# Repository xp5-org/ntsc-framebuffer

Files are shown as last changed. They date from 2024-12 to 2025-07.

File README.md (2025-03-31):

NTSC framebuffer built around 74x cmos logic gates and an 128k x 8bit sram module 

** this is incomplete and not yet built, in-progress **

- 8 bits for color + brightness
- 17 bits address
- transfer data in during vblank period

Tasks remaining:
  - complete memory addressing circuitry
  - check gate timings for brightness & color control paths
  - place adjustment potentiometers for setting PNP transistor bias
  - distribute ceramic capacitors
  - add debug testpads onto pcb

# Table of Contents
- [Current PCB Layout](#current-pcb-layout)
- [H&V Counter](#hvcounter)
- [HRESET](#hreset)
- [VRESET](#vreset)
- [HBLANK](#hblank-hsync)
- [VBLANK](#vblank-vsync)
- [COLORBURST](#colorburst)
- [COLORSELECT](#colorselect)
- [BRIGHTNESS](#brightness)
- [MEMORYANDBUS](#memoryandbus)
- [Output Amplifier](#outputamp)
- [Components selection](#components)
- [Simulating](#simtools)

# Current PCB Layout
pcb_infographic
<br>
pcb_infographic_3d
<br><br><br><br><br><br><br><br> 

# hvcounter
This is the core of the circuit, its two 4040 counters, one driving the other. the first counts out 454 which is the number of inactive + active horizontal pixels per row. the output is binary, and with enough AND gates alongside numerous D type flipflops, specific events can be timed out and set to form the sync timings needed

hv_counter_schematicblock

<br><br><br><br><br><br><br><br> 

# HRESET
Screenshot 2025-03-30 at 7 25 06 PM
256 + 128 + 64 + 4 + 2
counts out 454 horizontal & sets HRESET flag to high 5V
and on the next clock pulse from not the timer we are resetting but the actual clock source

<br><br><br><br><br><br><br><br> 

# VRESET
Screenshot 2025-03-30 at 7 37 49 PM
vreset is 1V + 4V + 256V for 261 vertical lines before resetting the counter

vertical reset is checked at the end of the horizontal scanline, so we use _HRESET as the clock for vreset - the condition of 261V lines is set only when _HRESET is ready

# HBLANK-HSYNC
Screenshot 2025-03-30 at 7 38 18 PM
Screenshot 2025-03-30 at 7 38 24 PM

the circuit starts off with some DC bias to give a sync tip from the "previous" scanline, and then at H2 + H8 HBLANK-ENABLE flop is cycled on. When this is on, elsewhere in the circuit the bias is cut off and gives us the horizontal sync tip

When H2 + H8 + H32 is seen (H42) , HBLANK_DISABLE is turned on, which is a 2nd flop "HSYNC B"
Screenshot 2025-03-30 at 8 22 18 PM

this lets me chain the hsync events together with explicit start and stop events, block them from re-triggering

<br><br><br><br><br><br><br><br> 

# VBLANK-VSYNC
Screenshot 2025-03-30 at 7 39 06 PM

<br><br><br><br><br><br><br><br> 

# COLORBURST
Screenshot 2025-03-30 at 7 39 46 PM
Screenshot 2025-03-30 at 7 39 58 PM

<br><br><br><br><br><br><br><br> 

# COLORSELECT
Screenshot 2025-03-30 at 7 41 10 PM
Screenshot 2025-03-30 at 7 41 23 PM
Screenshot 2025-03-30 at 7 41 27 PM

the 4-16 mux is often used for memory addressing and is only available in active-low, so in this case im using NOR gates to invert the signal . the MUX outputs are always high-inactive, so all NOR gates except for the active one are getting a positive voltage which turns them all off, exxcept for the active-low received from the MUX, this NOR gate switches on and provides a color clock at specific delays introduced by the 74AHC451's 4-5ns gate propigation delay
<br><br><br><br><br><br><br><br> 

# BRIGHTNESS
Screenshot 2025-03-30 at 7 42 30 PM
Screenshot 2025-03-30 at 7 42 13 PM

<br><br><br><br><br><br><br><br> 

# MEMORYANDBUS
Screenshot 2025-03-30 at 7 43 53 PM
Screenshot 2025-03-30 at 7 43 57 PM
<br><br><br><br><br><br><br><br> 

# outputamp
The output-amplifier interfaces the low-current, low impedience CMOS or TTL logic with the 1.4v, 75-ohm composite. 

HSYNC, Colorburst, and Pixel Input are given to the amplifiers input. Its first passed through a 2n7000 N-channel mosfet which inverts the signal. This drives a PNP transistor to return it back to positive output, this allowed the GND of the composite-out to also be the same reference plane as the GND of this circuit (pnp could be omitted and use only mosfet with resistor network and floating Gnd)

This has two additional mosfets for saturation bias and output voltage reduction (brightness).  The saturation mosfet biases the PNPs turnoff point "upwards" so that its off point rises above what hsync/hblank would have been . this serves the purpose of adding DC bias to reduce the modulation of the output without affecting the output peak (overall brightness). in summary, this is an amplifier which can control the height of the bottoms and tops of the wave output separately. its needed for color, but could dispose of half the mosfets if it were used for monochrome

Screenshot 2025-03-30 at 8 08 37 PM

<br><br><br><br><br><br><br><br> 

# Components
- 74HC74 D-FLOP
- 74HC08 AND
- 74HC02 NOR
- 74hc244 buffers
- 74hc154 4-to-16 mux
- 74ahc541 inv buffers (color delay line)
- CD4040 12 bit counter
- 14.318mhz crystal
- 128x8 sram HM628128DLP-5
- 2n5087 pnp or equivalent
- 2n7000 mosfet
- 7805 regulator

<br><br><br><br><br><br><br><br> 

# simtools

[LTSpice Model of Output Amplifier](./ltspice_sim/video_output_amplifier.asc)

[Digital Logic simulation](./Digital_sim/ntsc_gen.dig)

output amplifier in ltspice, showing peak brightness vs minimum brightness pixels , there is some distortion in the sim. Some gates are switching on/off before others and causing brief voltage spikes, this might be ignorable on the physical circuit ill have to go through the circuit flow to see what the issue is


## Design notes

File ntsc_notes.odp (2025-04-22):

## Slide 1

NTSC video circuit

Needed a device to scan through a memory chip and put an image on a screen

Wanted it to be universal so it could be adapted to an fgpa, arduino, appleii or whatever

I have an old 70s tv I wanted to use with a tv typewriter style system but didn’t want to use any specific custom impossible to find chips, instead wanted something that could be made out of VHDL or discrete components just as easy in either direction

Also had a number of extra 128k x 8-bit hitachi 70ns SRAM chips and built a project around this

Project can take two directions,

- either a single/multi display monochrome, or only 1 color display. Color info uses a lot more bits than monochrome

The output amplifier stage could be copied & pasted 8x and set each bit from the 1 byte memory to represent 8 different monochrome screens

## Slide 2

What is NTSC

Color Television Simplified Theory and Service Techniques ( Donald G Fink / Philco)

- https://web.archive.org/web/20240521005611/https://www.worldradiohistory.com/BOOKSHELF-ARH/Technology/Technology-General/Color-Television-Simplified-Theory-Philco-19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

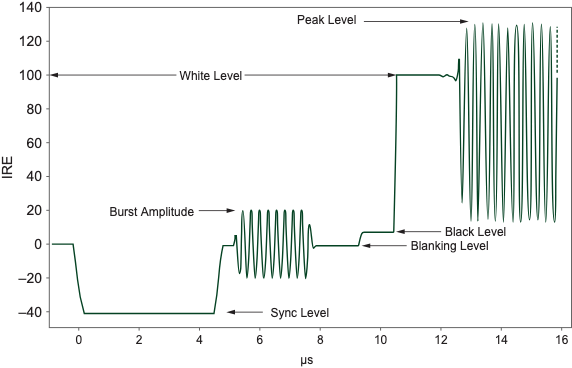
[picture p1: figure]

There is a 300 page philco book about NTSC in great detail, I wont even attempt to repeat what is said in it

Its difficult to avoid discussing what NTSC is – when reviewing over an NTSC video card circuit and how it was built. There is a lot of information online about the history of NTSC, why it is the way it is. but as far as “What it is” – its all in this simplified waveform diagram

in summary:

Its a DC-biased high frequency analog signal , 1.4v peak-to-peak with a negative pulse to synchronize the receiver at roughly 15khz. The Receiving CRT tv aligns itself to this HSYNC pulse each horizontal row of pixels (each scanline) so it knows when its time start drawing & when to advance down the next row

Atop of this HSYNC period, if color is used, is a 2nd sync pulse (Colorburst) to start the timer of an analog circuit related to color in the receiver. When colorburst is present , a color receiver will look at the pixel pulses/signal, and depending on what the phase-shift is of that signal (in reference to its own timer that was just synchronized moments ago), it will “move” or position the drawing on the screen to overlap either the RGB phosphors

When the receiving tv sees this “hblank” pulse, it uses the levels right after to set its various analog circuits, so they know what their turn off levels are (full-dark). On this blanking level is where color magic is shoehorned in

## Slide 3

Color in NTSC is determined by the amount of phase-shift, between the colorburst reference signal and the signal received for a given pixel. NTSC doesn’t have concepts of pixels, its just a analog voltage appearing on a line and then decaying at set intervals which roughly correspond to different positions on the screen (which we can call pixels) but mechanically speaking its a stopwatch paired to a trio of R/G/B laserbeams. HSYNC starts the stopwatch1 (draw the pixels timer) , and colorburst starts stopwatch2 (bias the output voltages left or right)

this rise-and-fall of pixel data, is drawn against an oscillator previously locked to the colorburst reference and any phase shift here will be pushing the point of luminosity left-or-right , thus shifting the color in the pattern represented by the following “NTSC color wheel”. So, the phase-shift represents the HUE of the color we see (with 1:1 lock to the reference being equal red-green-blue, or what we would perceive as white)

to be clear the electron beam is not moved or altered by colorburst. It is simply that the voltage-peak is higher earlier-or-later, at the time when its no longer perfectly overlapping the 3 RGB cells, so a 90 degree shift will have 2 half-blues 1 red and 1 green illuminated in perspective from starting at white.

Analogy: Imagine a person listening to an echo at a tunnel with a stopwatch on a gameshow. The show has a big wooden spinning color wheel which begin rotating by a motor when the show host fires a starting pistol (the colorburst timer). The longer the delay between the original sound and the echo, the more “time” translates to color shift and when the echo is herd the person stops the color wheel, and the color they land on is their score. The wheel never stops spinning, and the starting pistol is only fired once per round, so the contestant is reliant upon their stopwatch for good accurate scores

do this enough and can see that different colors happen at different exact predictable times (echos) given the tunnel length & wheel speed (clock frequency) stays the same. This is an analog way to convey lots of info (full color pallet)

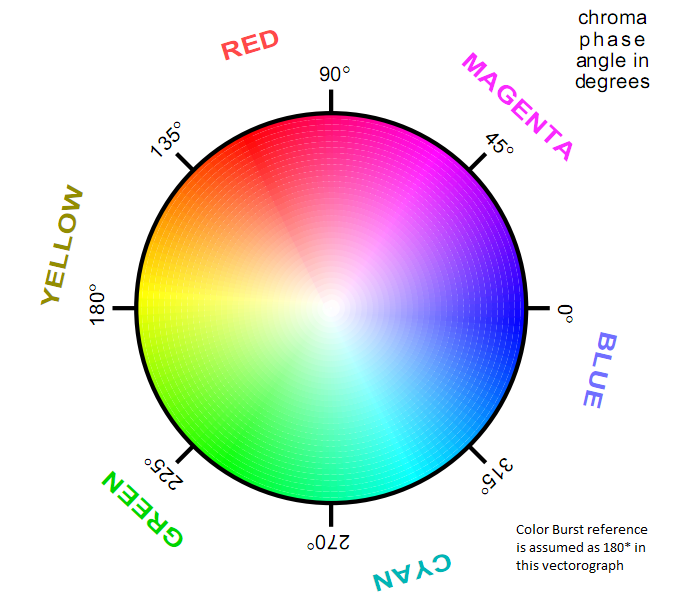
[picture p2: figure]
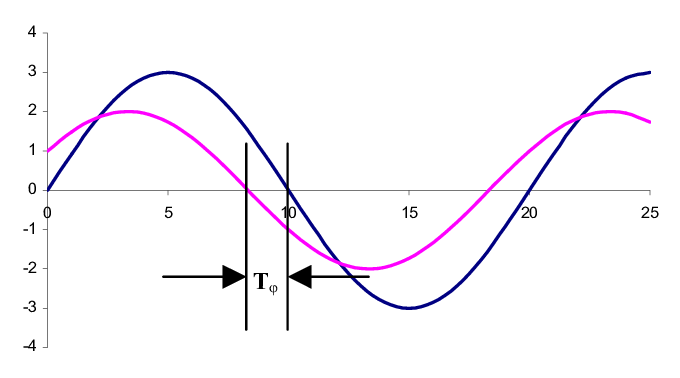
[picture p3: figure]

Phase shift of input pixel data changes appearance of timing of output to the electron guns so we are shifting left or right the intensity of the beam against phosphor **but not the beam itself**

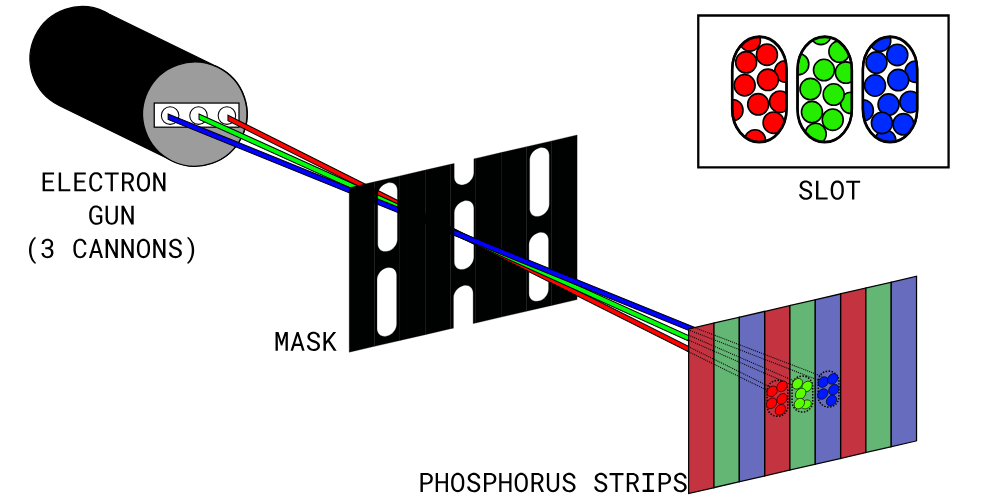
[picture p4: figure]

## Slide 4

https://www.rfcafe.com/references/radio-news/color-tv-ntsc-system-radio-television-news-april-1954.htm

NTSC color wheel in references look like this

red is (BY) – 103, or (RY) - 13

Yellow is (BY) – 167

Yellow also (-BY) + 13

Green (-BY) -61
Blue (BY) – 13

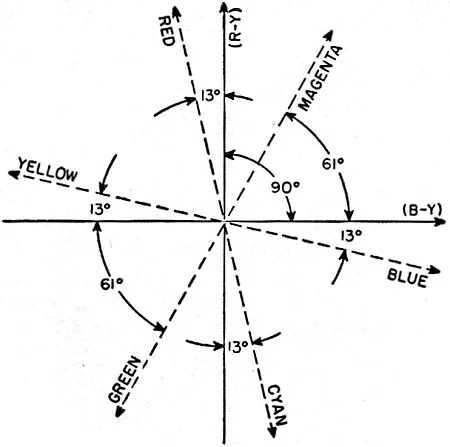
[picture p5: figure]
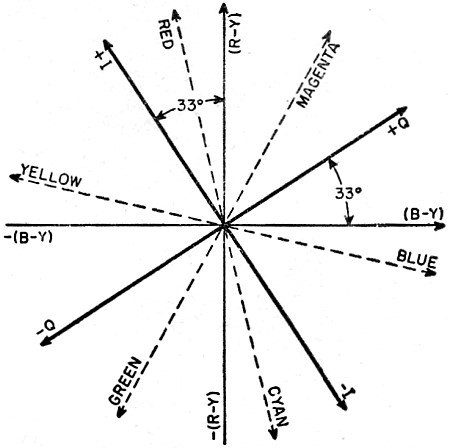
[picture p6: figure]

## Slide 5

Emphasis on: “the electron beam is not moved or altered”

We can’t (thats not how it works)

The CRT uses electromagnetic deflection coils which are very heavy components electrically, these are cycled at roughly 15khz . “pixels” on the screen are nearly 4mhz, so if we want to influence anything to do with pixels and how they appear on screen we have to rely on only this:

- changing beam intensity at specific points in time (electron gun is tiny and fast)

NTSC was designed to accommodate CRT display tubes, this means every design consideration is there to accommodate the mechanical behaviors of CRTs

- electron beam, phosphor screen, timings, color levels

For those using a modern display : None of this is directly useful to an LCD screen, so an LCD screen with composite in will be using an analog-digital type circuit to read the voltages at specific times and determine what a pixel is and what color it probably is. The artifacting and accuracy of what is shown will vary

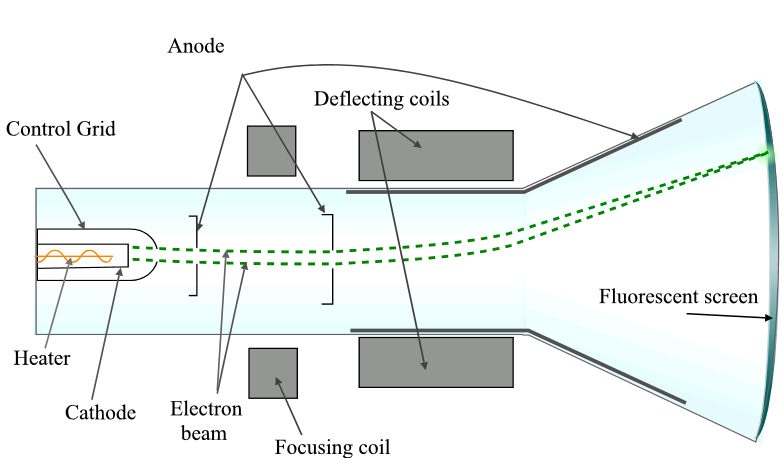
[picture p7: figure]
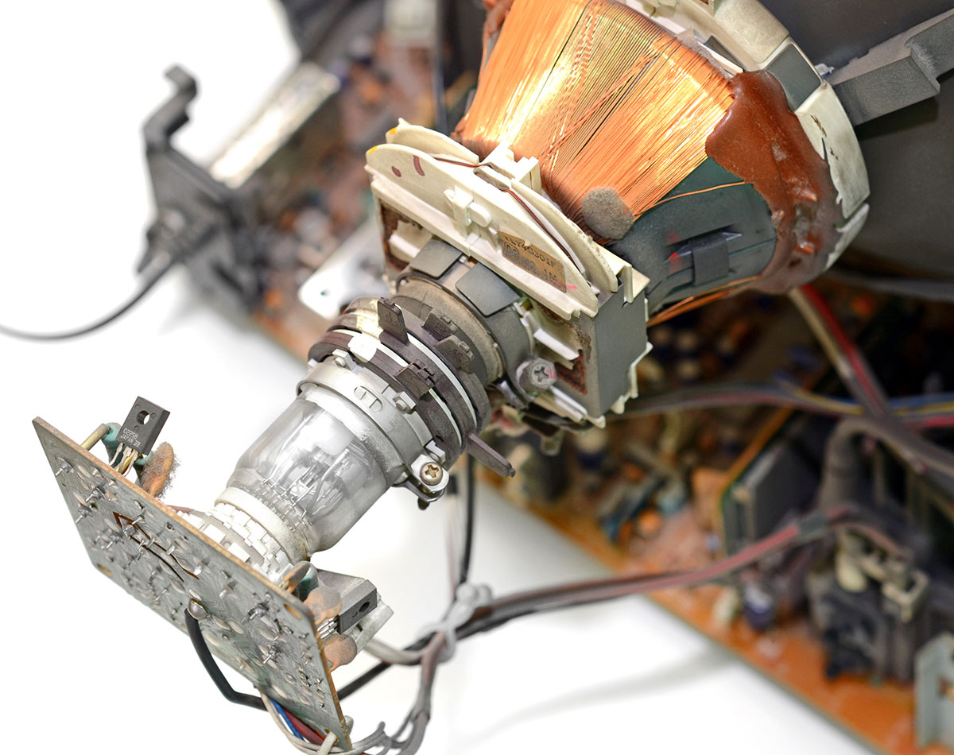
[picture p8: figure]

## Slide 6

Ive shown the NTSC color wheel from a 2D view, but that isnt the full story. NTSC has the concepts of “brightness” and “Saturation” as representation of signal intensities. But in the 2d view notice it is brighter or more pastel in the center

Here im showing the 2D color view, and the 3D reality which happens with over-saturation or overdrive

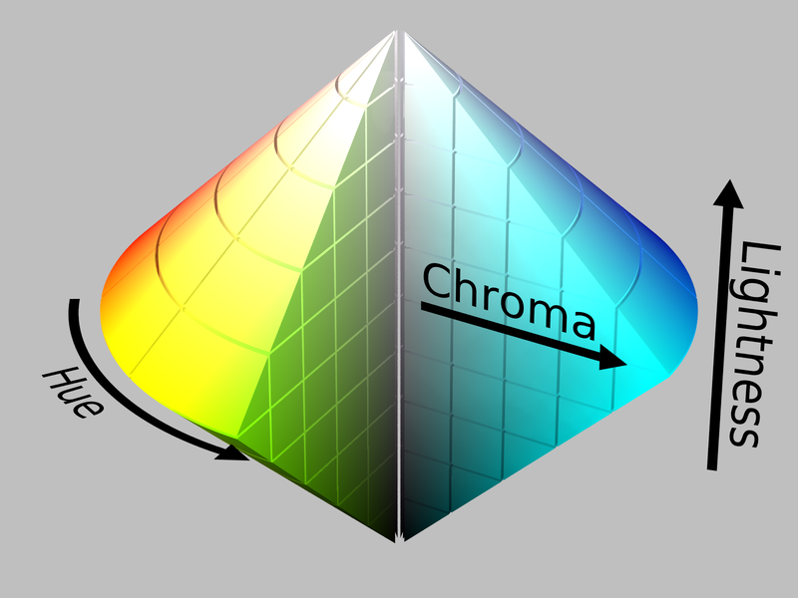
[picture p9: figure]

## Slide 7

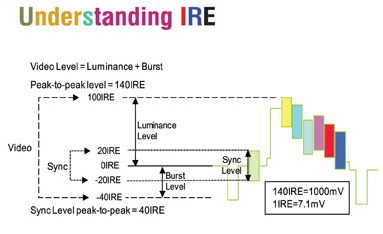
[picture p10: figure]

To discuss the 3d NTSC cone shape, need to go over the levels. More intensity doesn’t exactly mean “more of whatever color is happening right now”, it can mean (especially on a CRT set) color bleedover into adjacent cells as what might’ve been intended to be 50% cell1 50% cell2 illumination with proper biasing, too much intensity could result in 100% cell1 and 100% cell2 which results in the WRONG COLOR

With the HSYNC period having set the “black level” (which is the period at which the electron beam is turned off by its analog amplifier inside the receiver tv)

NTSC is originally a black and white concept with color added on as not a topic of levels, but one of phase-shift as we saw previously.

This is done by changing the MODULATION of the output signal, as in, keeping the peak voltage high but raising the DC bias upwards, reduces saturation and reduces the influence of this colorburst phase-shift making the image appear more gray and, well, less saturated.

So in review NTSC has these 3 key things:

HSYNC timing (start + stop time period, voltage level) – This sets when each new scanline starts and gets the show started and must be microsecond precise

Signal height (bias + peak to peak measurement) – translates to electron gun beam intensity or brightness. Its 0-1.4v

Signal amplitude (peak-to-peak, disregard bias) : More amplitude = less gray, less amplitude = more gray. controls amount of time/intensity electron beam is kept “away” from turnoff point and results in color cells always getting some intensity, which ‘grays’ out the image

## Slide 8

Going further into saturation & levels, different colors have requirements for both biasing the DC floor upwards (reduce saturation) or lowering it below black levels.

Red, Blue need to be modulated less than yellow or cyan, but have a lower starting point – this translates to less intensity on the electron beam and is nearly turning off, has to do with how the colors on a CRT phosphors are blending in

yellow and cyan are red + blue but need to keep the electron guns drive hot and vibrant almost white, so these colors are “biased upwards”

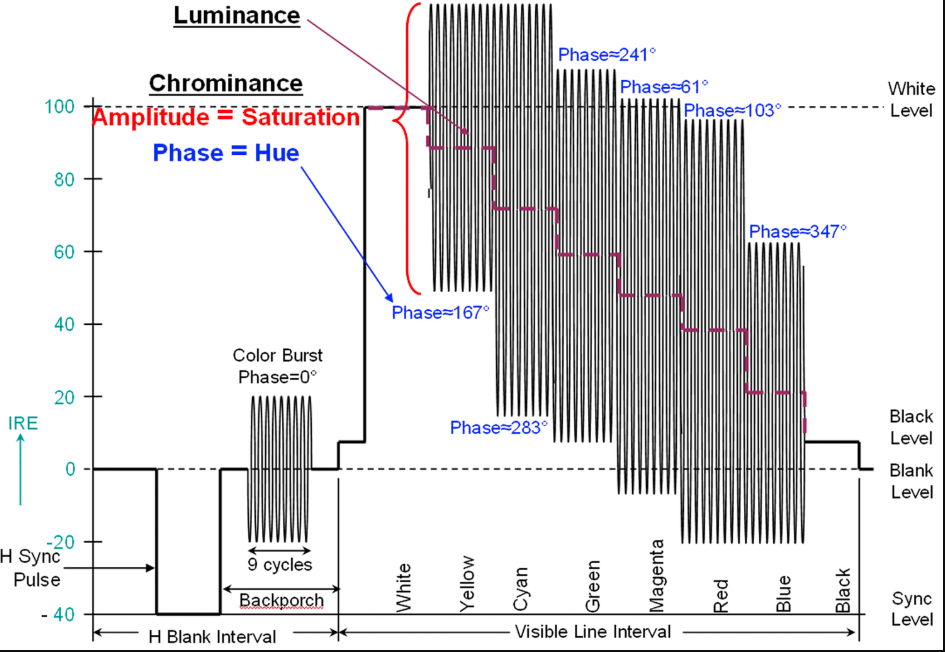
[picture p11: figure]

When you look at things like this, color on NTSC really seems like someone just slapped in a phosphor grid into a B&W set and used a few tricks to make the beam blink in the right spot at the right time.

Its clever but there are a lot of layers of cleverness to unpack

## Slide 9

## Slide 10

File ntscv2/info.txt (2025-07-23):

/ntscv2$ grep '(global_label' ntscv2.kicad_sch | sed -n 's/.*"\([^"]*\)".*/\1/p' | sort | uniq -c | sort -n | tail -n15
      4 H4
      4 H64
      4 HSYNCB
      4 m1_data4
      4 m1_data5
      4 m1_data6
      4 m1_data7
      4 PIXELDRAWEN
      5 H8
      6 H1
      6 H2
      6 VRESET
      7 CDL_output_enable
      8 _HRESET
      9 _VBLANK_BUFFERED

shows number of gates connected to a global label to get an idea for fanout load

READ:
CS1 - L
CS2 - H
OE - L
WE - H

WRITE:
READ:
CS1 - L
CS2 - H
OE - L or H
WE - L

A write occurs during the overlap of a low CS1, a high CS2, and a low WE. A write begins at the
latest transition among CS1 going low, CS2 going high, and WE going low. A write ends at the
earliest transition among CS1 going high, CS2 going low, and WE going high. tWP is measured
from the beginning of write to the end of write

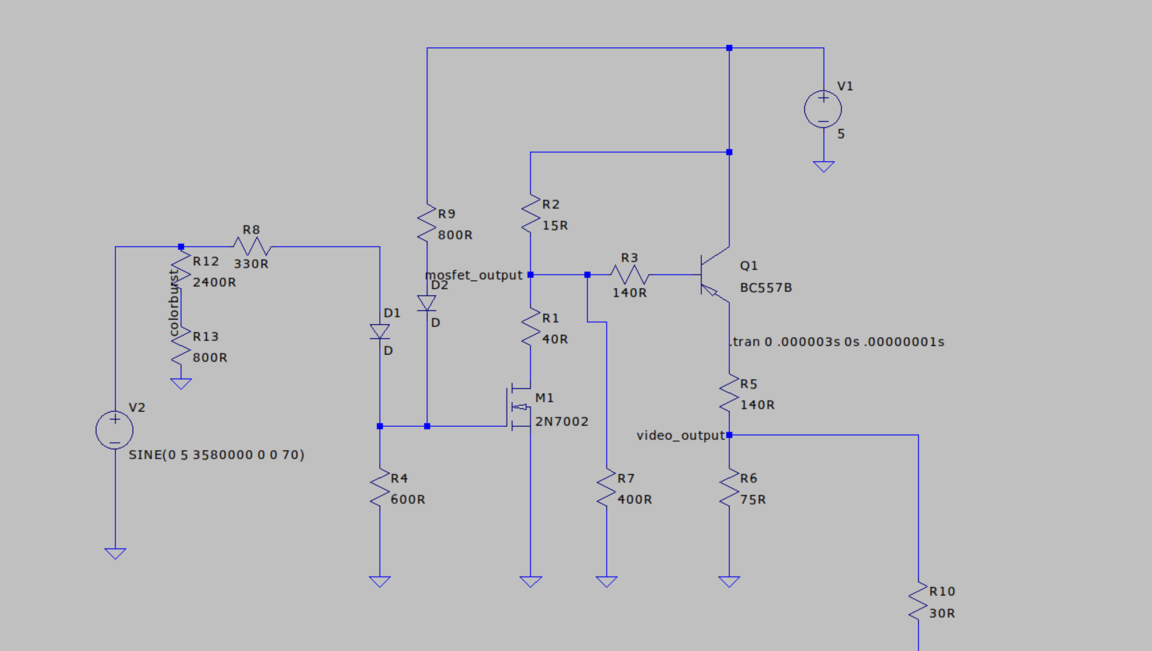
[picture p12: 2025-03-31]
ltspice_sim/BC557B_scematic.png

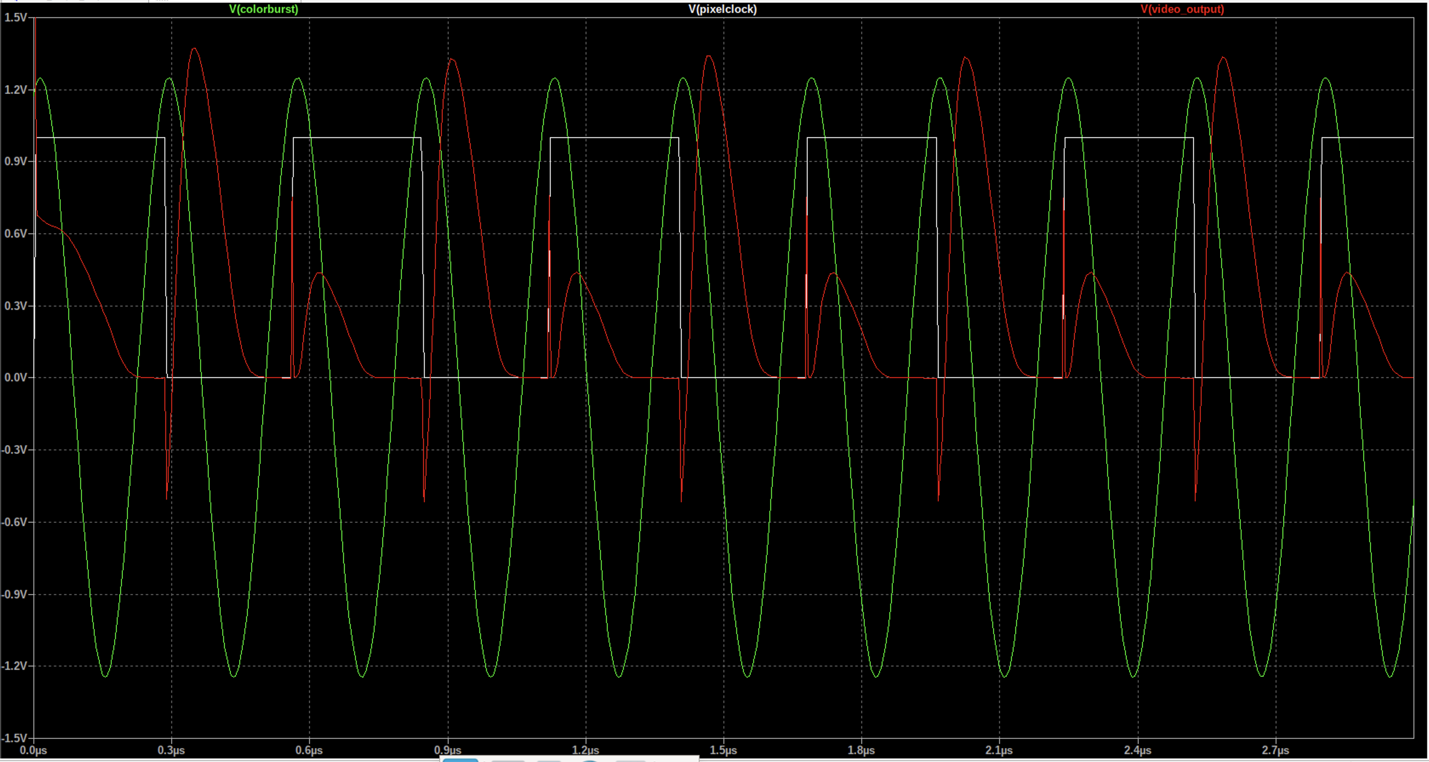
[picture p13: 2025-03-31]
ltspice_sim/BC557B_waveform.png

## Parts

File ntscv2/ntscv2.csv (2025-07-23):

Reference | Qty | Value | DNP | Exclude from BOM | Exclude from Board | Footprint | Datasheet
C3,C4,C5,C6,C7,C8,C9,C10,C11,C12,C13,C14,C15,C17,C19,C20,C21,C22,C23,C24,C25,C26,C27,C28,C29,C30,C31,C32,C33,C34,C35,C36,C37,C38,C39,C40,C41 | 37 | C |  |  |  | Capacitor_SMD:C_0603_1608Metric | ~
R30,R33,R35,R36,R37,R38,R39,R40,R41,R42,R43,R44,R45,R46,R47,R48,R49,R50,R51,R52,R53,R54,R55,R56,R57,R58,R59,R60,R61,R62,R63,R64,R65,R66,R67,R68 | 36 | 10k |  |  |  | Resistor_SMD:R_0402_1005Metric_Pad0.72x0.64mm_HandSolder | ~
D6,D7,D8,D9,D10,D11,D12,D13,D14,D15,D16,D17,D18,D19,D20,D21,D22,D23,D24,D25,D26,D27,D28,D29,D30,D31,D32,D33,D34,D35,D39 | 31 | 1N4148 |  |  |  | Diode_SMD:D_SOD-323 | https://assets.nexperia.com/documents/data-sheet/1N4148_1N4448.pdf
R9,R10,R15,R16,R17,R18,R19,R20,R21,R22,R23,R24,R25,R26,R27,R28,R29 | 17 | R |  |  |  | Resistor_SMD:R_0603_1608Metric | ~
R2,R3,R4,R5,R6,R7,R11,R12,R13,R14 | 10 | R |  |  |  | Resistor_THT:R_Axial_DIN0204_L3.6mm_D1.6mm_P5.08mm_Horizontal | ~
D1,D2,D3,D4,D5,D36,D37,D38,D41,D42 | 10 | 1N4448 |  |  |  | Diode_SMD:D_SOD-323 | https://assets.nexperia.com/documents/data-sheet/1N4148_1N4448.pdf
U5,U6,U7,U12,U13,U14,U27,U29,U31 | 9 | 74HC244 |  |  |  | Package_SO:TSSOP-20_4.4x6.5mm_P0.65mm | https://assets.nexperia.com/documents/data-sheet/74HC_HCT244.pdf
C42,C43,C44,C45,C46,C47,C48,C49 | 8 | 20uF 16v |  |  |  | Capacitor_SMD:C_1206_3216Metric | ~
U1,U2,U3,U4,U15,U16,U38 | 7 | 74AHC08D |  |  |  | Package_SO:SO-14_3.9x8.65mm_P1.27mm | http://www.intersil.com/content/dam/Intersil/documents/cd40/cd4073bms-81bms-82bms.pdf,https://jlcpcb.com/partdetail/Nexperia-74AHC08D118/C5506
U8,U9,U10,U11,U19 | 5 | 74HCT74 |  |  |  | Package_SO:SO-14_3.9x8.65mm_P1.27mm | https://www.ti.com/lit/ds/symlink/sn74hc74.pdf
U32,U33,U36,U37 | 4 | 74HC02 |  |  |  | Package_SO:SOIC-14_3.9x8.7mm_P1.27mm | http://www.ti.com/lit/gpn/sn74hc02,https://jlcpcb.com/partdetail/Nexperia-74HC02PW118/C113211
U18,U21,U23,U24 | 4 | 4040 |  |  |  | Package_SO:SOIC-16W_5.3x10.2mm_P1.27mm | http://www.intersil.com/content/dam/Intersil/documents/cd40/cd4020bms-24bms-40bms.pdf
H1,H2,H3,H4 | 4 | MountingHole_Pad |  | Excluded from BOM |  | MountingHole:MountingHole_2.7mm_M2.5_DIN965_Pad | ~
RV1,RV2,RV4 | 3 | R_Potentiometer |  |  |  | mysymbols_footprint:TRIM_3362P-1-100LF | ~
R31,R32,R34 | 3 | 10k |  |  |  | Resistor_SMD:R_0603_1608Metric | ~
Q1,Q2,Q4 | 3 | 2N7000 |  |  |  | Package_TO_SOT_THT:TO-92_Inline | https://www.vishay.com/docs/70226/70226.pdf
U34,U35 | 2 | 74HC540D_653 |  |  |  | Package_SO:SOIC-20W_7.5x12.8mm_P1.27mm
U26,U30 | 2 | 74HC154PW |  |  |  | Package_SO:TSSOP-24_4.4x7.8mm_P0.65mm | https://jlcpcb.com/partdetail/Nexperia-74HC154PW118/C21061,https://www.ti.com/lit/ds/symlink/cd74hc154.pdf
U22,U25 | 2 | 74HC04 |  |  |  | Package_SO:SOIC-14_3.9x8.7mm_P1.27mm | https://assets.nexperia.com/documents/data-sheet/74HC_HCT04.pdf
C50,C51 | 2 | 10uF 25V |  |  |  | Capacitor_SMD:C_1206_3216Metric | ~
C1,C2 | 2 | 15pF |  |  |  | Capacitor_SMD:C_0603_1608Metric | ~
Y1 | 1 | Crystal |  |  |  | Crystal:Crystal_HC49-U_Vertical | ~
U28 | 1 | LM7805_TO220 |  |  |  | Package_TO_SOT_THT:TO-220-3_Vertical | https://www.onsemi.cn/PowerSolutions/document/MC7800-D.PDF
U20 | 1 | 74HC245D |  |  |  | Package_SO:TSSOP-20_4.4x6.5mm_P0.65mm | https://www.nexperia.com/product/74HC245D
U17 | 1 | HM628128ALFP-5 |  |  |  | Package_DIP:DIP-32_W15.24mm
TP88 | 1 | FIELD0 |  |  |  | mysymbols_footprint:TestPoint_Pad_0.8x0.8mm | ~
TP87 | 1 | FIELD1 |  |  |  | mysymbols_footprint:TestPoint_Pad_0.8x0.8mm | ~
TP86 | 1 | CB_DIS |  |  |  | mysymbols_footprint:TestPoint_Pad_0.8x0.8mm | ~
TP85 | 1 | CBEN |  |  |  | mysymbols_footprint:TestPoint_Pad_0.8x0.8mm | ~
TP84 | 1 | PIXELDRAWEN |  |  |  | mysymbols_footprint:TestPoint_Pad_0.8x0.8mm | ~
TP83 | 1 | VRESET |  |  |  | mysymbols_footprint:TestPoint_Pad_0.8x0.8mm | ~
TP82 | 1 | HRESET |  |  |  | mysymbols_footprint:TestPoint_Pad_0.8x0.8mm | ~
TP81 | 1 | VBLANK |  |  |  | mysymbols_footprint:TestPoint_Pad_0.8x0.8mm | ~
TP80 | 1 | HSYNCA |  |  |  | mysymbols_footprint:TestPoint_Pad_0.8x0.8mm | ~
TP79 | 1 | HSYNCB |  |  |  | mysymbols_footprint:TestPoint_Pad_0.8x0.8mm | ~
TP7 | 1 | HSYNC_input |  |  |  | mysymbols_footprint:TestPoint_Pad_0.8x0.8mm | ~
TP6 | 1 | Pixeldrive_input |  |  |  | mysymbols_footprint:TestPoint_Pad_0.8x0.8mm | ~
TP5 | 1 | CB_Source |  |  |  | mysymbols_footprint:TestPoint_Pad_0.8x0.8mm | ~
RV3 | 1 | 100R |  |  |  | mysymbols_footprint:TRIM_3362P-1-100LF | ~
R8 | 1 | ~ |  |  |  | Resistor_SMD:R_0603_1608Metric | ~
R1 | 1 | 6k |  |  |  | Resistor_SMD:R_0603_1608Metric | ~
Q3 | 1 | BC327 |  |  |  | Package_TO_SOT_THT:TO-92_Inline | http://www.onsemi.com/pub_link/Collateral/BC327-D.PDF
J3 | 1 | Conn_01x02 |  |  |  | Connector_PinHeader_2.54mm:PinHeader_1x02_P2.54mm_Vertical | ~
J2 | 1 | Conn_Coaxial |  |  |  | Connector_Coaxial:BNC_TEConnectivity_1478035_Horizontal | ~
J1 | 1 | Conn_02x20_Odd_Even |  |  |  | Connector_PinHeader_2.54mm:PinHeader_2x20_P2.54mm_Vertical | ~

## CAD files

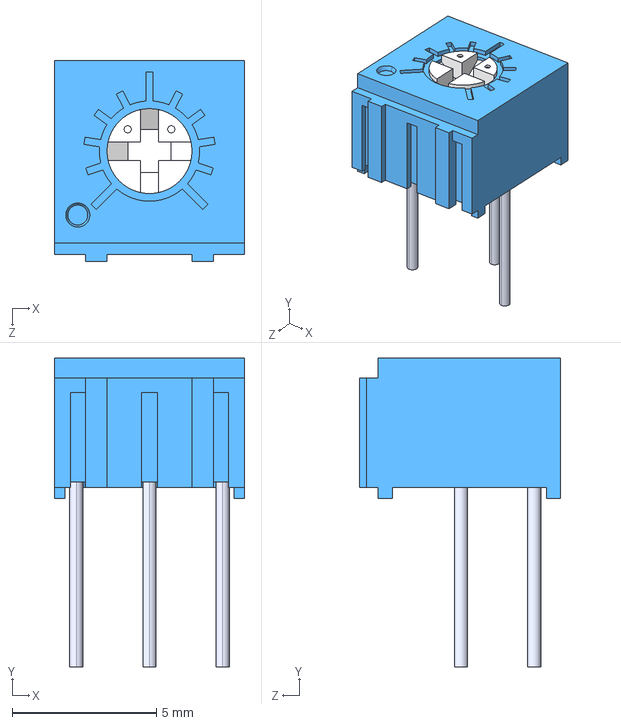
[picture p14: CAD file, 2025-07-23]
ntscv2/3362P-1-100LF.step
6.60 x 10.7 x 6.99 mm

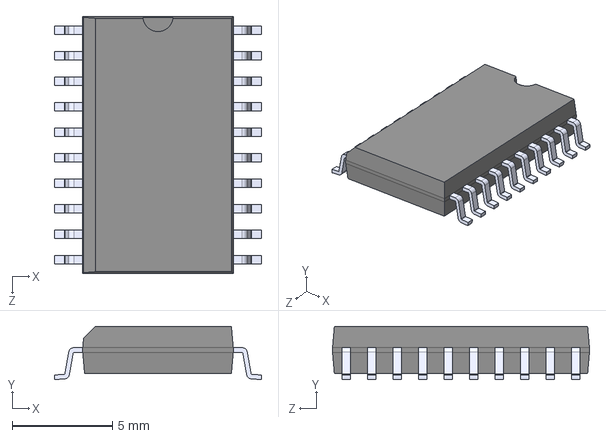
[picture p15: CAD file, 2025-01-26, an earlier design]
old_deletesoon/ntsc_syncgen_kicad/downloaded_symbols/74HC540D_653/74HC540D_653.step
10.3 x 2.65 x 12.8 mm

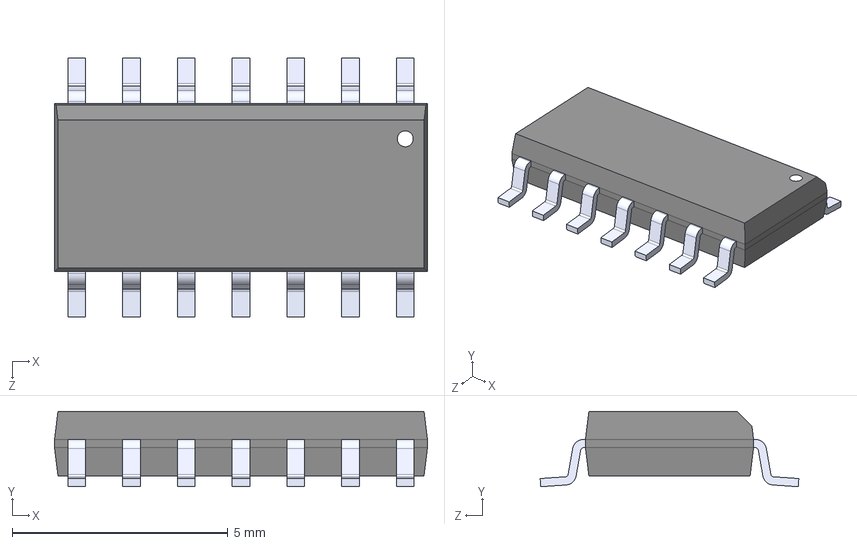
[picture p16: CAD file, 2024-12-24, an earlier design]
old_deletesoon/ntsc_syncgen_kicad/downloaded_symbols/SN74AHC74DR/SN74AHC74DR.step
8.65 x 1.75 x 6.00 mm

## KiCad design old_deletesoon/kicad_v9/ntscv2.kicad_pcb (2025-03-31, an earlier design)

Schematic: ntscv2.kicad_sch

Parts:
C1, C4, C5, C6, C7, C8, C9, C10, C11, C12, C13, C14, C15, C16, C17, C18, C19, C20, C21, C22, C23, C24, C25, C27: C; C_Disc_D5.1mm_W3.2mm_P5.00mm
C2, C3: 10pF; C_Disc_D3.0mm_W2.0mm_P2.50mm
C26: C; C_Radial_D8.0mm_H7.0mm_P3.50mm
D1, D2, D3, D4, D5: 1N4448; D_DO-35_SOD27_P7.62mm_Horizontal
D6, D7, D8, D9, D10, D11, D12, D13, D14, D15, D16, D17, D18, D19, D20, D21, D22, D23, D24, D25, D26, D27, D28, D29, D30, D31, D32, D33, D34, D35, D36: 1N4148; D_DO-35_SOD27_P7.62mm_Horizontal
J1: Conn_Coaxial; BNC_TEConnectivity_1478035_Horizontal
J2: Conn_02x04_Counter_Clockwise; PinSocket_2x04_P2.54mm_Vertical
J3: Conn_02x20_Counter_Clockwise; PinSocket_2x20_P2.54mm_Vertical
Q1: BC327; TO-92_Inline
Q2, Q3, Q4: 2N7000; TO-92_Inline
R1, R3, R4, R5, R6, R7, R8, R9, R10, R11, R12, R13, R14, R15, R16, R17, R18, R19, R20, R21, R22, R23, R24, R25, R26, R27, R28, R29, R30: R; R_Axial_DIN0204_L3.6mm_D1.6mm_P5.08mm_Horizontal
R2: 680; R_Axial_DIN0204_L3.6mm_D1.6mm_P7.62mm_Horizontal
R31, R32, R33: 50R; R_Axial_DIN0204_L3.6mm_D1.6mm_P5.08mm_Horizontal
U1, U2, U3, U4, U5, U40: 74HCT74; SO-14_3.9x8.65mm_P1.27mm
U6, U7, U14, U15: 4040; DIP-16_W7.62mm_SMDSocket_SmallPads
U8: 74HC7014; SOIC-14_3.9x8.7mm_P1.27mm
U9, U10, U11, U13: 4081; DIP-14_W7.62mm
U12: 4081; SO-14_3.9x8.65mm_P1.27mm
U16, U30: 74154; SOIC-24W_7.5x15.4mm_P1.27mm
U17, U18, U21: 74AHC541; SOIC-20W_7.5x12.8mm_P1.27mm
U19, U20, U22, U23: 74HC02; SOIC-14_3.9x8.7mm_P1.27mm
U24, U25, U26, U27, U28, U29, U31, U32: 74HC244; SSOP-20_4.4x6.5mm_P0.65mm
U33: HM628128ALFP-5; DIP-32_W15.24mm; PARTREV 20/6/13
U34, U35: 74HC540D_653; SOIC-20W_7.5x12.8mm_P1.27mm; MPN 74HC540D,653
U46: LM7805_TO220; TO-220-3_Vertical
Y1: Crystal; Crystal_HC49-U_Vertical

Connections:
1H: U6.9 (Q0), U17.2 (A0), U19.2
1V: U7.9 (Q0), U10.1
2H: U6.7 (Q1), U9.1
2V: U7.7 (Q1)
4H: U6.6 (Q2), U9.2
4V: U7.6 (Q2), U10.5
5vdc: C1.1, C4.1, C5.1, C6.1, C7.1, C8.1, C9.1, C10.1, C11.1, C12.1, C13.1, C14.1, C15.1, C16.1, C17.1, C18.1, C19.1, C20.1, C21.1, C22.1, C23.1, C24.1, C25.1, C26.1, J2.1, J2.2, Q1.1 (C), R12.1, U1.10 (~S), U1.13 (~R), U1.14 (VCC), U2.10 (~S), U2.13 (~R), U2.14 (VCC), U3.2 (D), U3.4 (~S), U3.10 (~S), U3.12 (D), U3.14 (VCC), U4.2 (D), U4.4 (~S), U4.10 (~S), U4.12 (D), U4.14 (VCC), U5.2 (D), U5.4 (~S), U5.10 (~S), U5.12 (D), U5.14 (VCC), U6.16 (VDD), U7.16 (VDD), U8.14 (VCC), U9.14 (VDD), U10.14 (VDD), U11.14 (VDD), U12.14 (VDD), U13.14 (VDD), U14.16 (VDD), U15.16 (VDD), U16.24 (VCC), U17.20 (VCC), U18.20 (VCC), U19.14 (VCC), U20.14 (VCC), U21.20 (VCC), U22.14 (VCC), U23.14 (VCC), U24.20 (VCC), U25.20 (VCC), U26.20 (VCC), U27.20 (VCC), U28.20 (VCC), U29.20 (VCC), U30.24 (VCC), U31.20 (VCC), U32.20 (VCC), U33.32 (VCC), U34.20 (VCC), U35.20 (VCC), U40.1 (~R), U40.4 (~S), U40.10 (~S), U40.13 (~R), U40.14 (VCC), U46.3 (VO)
7.1mhz_CLK1: U1.5 (Q), U6.10 (CLK), U7.10 (CLK)
8H: U6.5 (Q3)
8V: U7.5 (Q3)
14mhz_CLK0: U1.3 (C), U2.3 (C), U8.6, U8.8, U8.10
16H: U6.3 (Q4)
16V: U7.3 (Q4)
32H: U6.2 (Q5)
32V: U7.2 (Q5)
64H: U6.4 (Q6), U9.5
64V: U7.4 (Q6)
128H: U6.13 (Q7), U9.6
128V: U7.13 (Q7)
256H: U6.12 (Q8), U9.13
256V: U7.12 (Q8), U10.6
512H: U6.14 (Q9)
512V: U7.14 (Q9)
BIAS_ADJ: J2.8, Q3.2 (G), R5.1
BRIGHTNESS: J2.7, Q4.2 (G), R6.1
CB_DISABLE: U5.9 (Q), U11.5
CB_ENABLE: U5.5 (Q), U12.8
CDL_output_enable: U16.18 (~E0), U16.19 (~E1), U17.1 (G1), U17.19 (G2), U18.1 (G1), U18.19 (G2), U21.1 (G1), U21.19 (G2), U30.18 (~E0), U30.19 (~E1), U34.1 (~OE), U34.19 (~OE2), U35.1 (~OE), U35.19 (~OE2)
FIELDCOUNTER: U40.2 (D), U40.6 (~Q)
GND: C1.2, C2.2, C3.2, C4.2, C5.2, C6.2, C7.2, C8.2, C9.2, C10.2, C11.2, C12.2, C13.2, C14.2, C15.2, C16.2, C17.2, C18.2, C19.2, C20.2, C21.2, C22.2, C23.2, C24.2, C25.2, C26.2, C27.2, J1.2 (Ext), J2.3, J2.4, J2.5, Q2.1 (S), Q3.1 (S), Q4.1 (S), R5.2, R6.2, R7.2, R11.2, R14.2, U1.7 (GND), U2.7 (GND), U3.7 (GND), U4.7 (GND), U5.7 (GND), U6.8 (VSS), U7.8 (VSS), U8.7 (GND), U9.7 (VSS), U10.7 (VSS), U11.7 (VSS), U12.7 (VSS), U13.7 (VSS), U14.8 (VSS), U15.8 (VSS), U16.12 (GND), U17.10 (GND), U18.10 (GND), U19.7 (GND), U20.7 (GND), U21.10 (GND), U22.7 (GND), U23.7 (GND), U24.10 (GND), U25.10 (GND), U26.10 (GND), U27.10 (GND), U28.10 (GND), U29.10 (GND), U30.12 (GND), U31.10 (GND), U32.10 (GND), U33.16 (VSS), U34.10 (GND), U35.10 (GND), U40.7 (GND), U46.2 (GND)
H2: U10.8, U11.12, U12.6
H4: U12.9
H8: U10.9, U11.6, U11.8
H16: U12.1
H32: U11.9, U12.2
H64: U12.13
HRESET: U2.5 (Q), U6.11 (Reset)
HSYNCA: U3.5 (Q)
HSYNCB: D2.2 (A), U3.9 (Q), U13.9
unnamed: C2.1, U8.1, Y1.1
unnamed: C3.1, R2.2, Y1.2
unnamed: D1.1 (K), U10.12
unnamed: D2.1 (K), U10.13
unnamed: D3.2 (A), U10.11
unnamed: D3.1 (K), R1.1
unnamed: D4.2 (A), U13.4
unnamed: D4.1 (K), R3.1
unnamed: D5.2 (A), U13.11
unnamed: D5.1 (K), R4.1
unnamed: D6.2 (A), U19.1
unnamed: D7.2 (A), U19.4
unnamed: D8.2 (A), U19.10
unnamed: D9.2 (A), U19.13
unnamed: D10.2 (A), U20.1
unnamed: D11.2 (A), U20.4
unnamed: D12.2 (A), U20.10
unnamed: D13.2 (A), U20.13
unnamed: D14.2 (A), U22.1
unnamed: D15.2 (A), U22.4
unnamed: D16.2 (A), U22.10
unnamed: D17.2 (A), U22.13
unnamed: D18.2 (A), U23.1
unnamed: D19.2 (A), U23.4
unnamed: D20.2 (A), U23.10
unnamed: D21.2 (A), R15.2
unnamed: D22.2 (A), R16.2
unnamed: D23.2 (A), R17.2
unnamed: D24.2 (A), R18.2
unnamed: D25.2 (A), R19.2
unnamed: D26.2 (A), R20.2
unnamed: D27.2 (A), R21.2
unnamed: D28.2 (A), R22.2
unnamed: D29.2 (A), R23.2
unnamed: D30.2 (A), R24.2
unnamed: D31.2 (A), R25.2
unnamed: D32.2 (A), R26.2
unnamed: D33.2 (A), R27.2
unnamed: D34.2 (A), R28.2
unnamed: D35.2 (A), R29.2
unnamed: D36.2 (A), R30.2
unnamed: Q1.2 (B), R9.2
unnamed: Q1.3 (E), R10.1
unnamed: Q2.3 (D), R8.2
unnamed: Q3.3 (D), R8.1, R9.1, R12.2, R14.1
unnamed: Q4.3 (D), R13.2
unnamed: R2.1, U8.2, U8.3
unnamed: U1.2 (D), U1.6 (~Q)
unnamed: U1.1 (~R), U1.4 (~S)
unnamed: U1.11 (C), U13.3
unnamed: U1.8 (~Q), U1.12 (D)
unnamed: U2.2 (D), U9.11
unnamed: U2.1 (~R), U2.4 (~S)
unnamed: U2.12 (D), U10.3
unnamed: U3.3 (C), U10.10
unnamed: U3.11 (C), U11.11
unnamed: U4.3 (C), U11.3
unnamed: U5.3 (C), U12.4
unnamed: U5.11 (C), U12.11
unnamed: U8.4, U8.5, U8.9, U8.11
unnamed: U9.3, U9.8
unnamed: U9.4, U9.9
unnamed: U9.10, U9.12
unnamed: U10.2, U10.4
unnamed: U11.2, U11.4
unnamed: U11.10, U11.13
unnamed: U12.3, U12.5
unnamed: U12.10, U12.12
unnamed: U13.10, U13.13
unnamed: U17.3 (A1), U17.18 (Y0)
unnamed: U17.4 (A2), U17.17 (Y1)
unnamed: U17.5 (A3), U17.16 (Y2)
unnamed: U17.6 (A4), U17.15 (Y3)
unnamed: U17.7 (A5), U17.14 (Y4)
unnamed: U17.8 (A6), U17.13 (Y5)
unnamed: U17.9 (A7), U17.12 (Y6)
unnamed: U17.11 (Y7), U18.9 (A7)
unnamed: U18.2 (A0), U18.17 (Y1)
unnamed: U18.3 (A1), U18.16 (Y2)
unnamed: U18.4 (A2), U18.15 (Y3)
unnamed: U18.5 (A3), U18.14 (Y4)
unnamed: U18.6 (A4), U18.13 (Y5)
unnamed: U18.7 (A5), U18.12 (Y6)
unnamed: U18.8 (A6), U18.11 (Y7)
unnamed: U18.18 (Y0), U21.2 (A0)
unnamed: U21.3 (A1), U21.18 (Y0)
unnamed: U21.4 (A2), U21.17 (Y1)
unnamed: U21.5 (A3), U21.16 (Y2)
unnamed: U21.6 (A4), U21.15 (Y3)
unnamed: U21.7 (A5), U21.14 (Y4)
unnamed: U21.8 (A6), U21.13 (Y5)
unnamed: U21.9 (A7), U21.12 (Y6)
unnamed: R15.1, U34.18 (~Y0)
unnamed: R19.1, U34.17 (~Y1)
unnamed: R23.1, U34.16 (~Y2)
unnamed: R27.1, U34.15 (~Y3)
unnamed: R16.1, U34.14 (~Y4)
unnamed: R20.1, U34.13 (~Y5)
unnamed: R24.1, U34.12 (~Y6)
unnamed: R28.1, U34.11 (~Y7)
unnamed: R17.1, U35.18 (~Y0)
unnamed: R21.1, U35.17 (~Y1)
unnamed: R25.1, U35.16 (~Y2)
unnamed: R29.1, U35.15 (~Y3)
unnamed: R18.1, U35.14 (~Y4)
unnamed: R22.1, U35.13 (~Y5)
unnamed: R26.1, U35.12 (~Y6)
unnamed: R30.1, U35.11 (~Y7)
unnamed: U40.5 (Q), U40.11 (C)
Output_Signal_75ohm: J1.1 (In), R10.2, R11.1, R13.1
PAGECOUNTER: U40.8 (~Q), U40.12 (D)
PIXELDRAWEN: U4.5 (Q), U13.6
PIXEL_INPUT_FROM_COLORARRAY: U13.5
V16: U4.11 (C)
VBLANK: R32.2, U4.9 (Q)
VRESET: U2.9 (Q), U7.11 (Reset), U14.11 (Reset), U15.11 (Reset), U40.3 (C)
_CB_DISABLE: U5.8 (~Q)
_CB_ENABLE: U5.6 (~Q)
_HRESET: U2.6 (~Q), U2.8 (~Q), U2.11 (C), U3.1 (~R), U3.13 (~R), U4.1 (~R), U5.1 (~R), U5.13 (~R)
_HSYNCA: D1.2 (A), U3.6 (~Q), U13.8
_HSYNCB: U3.8 (~Q)
_PIXELDRAWEN: U4.6 (~Q)
_VBLANK: R31.1, R33.2, U4.8 (~Q), U11.1, U13.2
_VRESET: U4.13 (~R)
ampinput: J2.6, Q2.2 (G), R1.2, R3.2, R4.2, R7.1
bus_addr0: J3.40, U29.11 (2A3)
bus_addr1: J3.39, U27.2 (1A0)
bus_addr2: J3.38, U27.4 (1A1)
bus_addr3: J3.37, U27.6 (1A2)
bus_addr4: J3.36, U27.8 (1A3)
bus_addr5: J3.35, U27.17 (2A0)
bus_addr6: J3.34, U27.15 (2A1)
bus_addr7: J3.33, U27.13 (2A2)
bus_addr8: J3.32, U27.11 (2A3)
bus_addr9: J3.31, U28.2 (1A0)
bus_addr10: J3.30, U28.4 (1A1)
bus_addr11: J3.29, U28.6 (1A2)
bus_addr12: J3.28, U28.8 (1A3)
bus_addr13: J3.27, U28.17 (2A0)
bus_addr14: J3.26, U28.15 (2A1)
bus_addr15: J3.25, U28.13 (2A2)
bus_addr16: J3.24, U28.11 (2A3)
bus_data0: J3.1, U31.2 (1A0)
bus_data1: J3.2, U31.4 (1A1)
bus_data2: J3.3, U31.6 (1A2)
bus_data3: J3.4, U31.8 (1A3)
bus_data4: J3.5, U31.17 (2A0)
bus_data5: J3.6, U31.15 (2A1)
bus_data6: J3.7, U31.13 (2A2)
bus_data7: J3.8, U31.11 (2A3)
bus_writeflag_9thbit: J3.9, R31.2, U13.1, U29.13 (2A2)
colorburst_delayline: D7.1 (K), D8.1 (K), D9.1 (K), D10.1 (K), D11.1 (K), D12.1 (K), D13.1 (K), D14.1 (K), D15.1 (K), D16.1 (K), D17.1 (K), D18.1 (K), D19.1 (K), D20.1 (K); also elsewhere on the board
colorburst_ref_colorwhite: D6.1 (K), U13.12
colordata_0: U16.23 (A0), U32.2 (1A0)
colordata_1: U16.22 (A1), U32.4 (1A1)
colordata_2: U16.21 (A2), U32.6 (1A2)
colordata_3: U16.20 (A3), U32.8 (1A3)
colordata_4: U30.23 (A0), U32.17 (2A0)
colordata_5: U30.22 (A1), U32.15 (2A1)
colordata_6: U30.21 (A2), U32.13 (2A2)
colordata_7: U30.20 (A3), U32.11 (2A3)
colorselect1: U16.1 (~S0), U19.3
colorselect2: U16.2 (~S1), U19.6
colorselect3: U16.3 (~S2), U19.9
colorselect4: U16.4 (~S3), U19.12
colorselect5: U16.5 (~S4), U20.3
colorselect6: U16.6 (~S5), U20.6
colorselect7: U16.7 (~S6), U20.9
colorselect8: U16.8 (~S7), U20.12
colorselect9: U16.9 (~S8), U22.3
colorselect10: U16.10 (~S9), U22.6
colorselect11: U16.11 (~S10), U22.9
colorselect12: U16.13 (~S11), U22.12
colorselect13: U16.14 (~S12), U23.3
colorselect14: U16.15 (~S13), U23.6
colorselect15: U16.16 (~S14), U23.9
colorselect16: U16.17 (~S15)
delayline2: U19.5
delayline3: U19.8
delayline4: U19.11
delayline5: U20.2
delayline6: U20.5
delayline7: U20.8
delayline8: U20.11
delayline9: U22.2
delayline10: U22.5
delayline11: U22.8
delayline12: U22.11
delayline13: U23.2
delayline14: U23.5
delayline15: U23.8
ext_bustoggle: R33.1, U27.1 (1OE), U27.19 (2OE), U28.1 (1OE), U28.19 (2OE), U29.1 (1OE), U29.19 (2OE), U31.1 (1OE), U31.19 (2OE)
inputvoltage: C27.1, U46.1 (VI)
int_bustoggle: R32.1, U24.1 (1OE), U24.19 (2OE), U25.1 (1OE), U25.19 (2OE), U26.1 (1OE), U26.19 (2OE), U32.1 (1OE), U32.19 (2OE)
luminosity_select1: U30.1 (~S0), U34.2 (A0)
luminosity_select2: U30.2 (~S1), U34.3 (A1)
luminosity_select3: U30.3 (~S2), U34.4 (A2)
luminosity_select4: U30.4 (~S3), U34.5 (A3)
luminosity_select5: U30.5 (~S4), U34.6 (A4)
luminosity_select6: U30.6 (~S5), U34.7 (A5)
luminosity_select7: U30.7 (~S6), U34.8 (A6)
luminosity_select8: U30.8 (~S7), U34.9 (A7)
luminosity_select9: U30.9 (~S8), U35.2 (A0)
luminosity_select10: U30.10 (~S9), U35.3 (A1)
luminosity_select11: U30.11 (~S10), U35.4 (A2)
luminosity_select12: U30.13 (~S11), U35.5 (A3)
luminosity_select13: U30.14 (~S12), U35.6 (A4)
luminosity_select14: U30.15 (~S13), U35.7 (A5)
luminosity_select15: U30.16 (~S14), U35.8 (A6)
luminosity_select16: U30.17 (~S15), U35.9 (A7)
m1_data0: U31.18 (1Y0), U32.18 (1Y0), U33.13 (I/O0)
m1_data1: U31.16 (1Y1), U32.16 (1Y1), U33.14 (I/O1)
m1_data2: U31.14 (1Y2), U32.14 (1Y2), U33.15 (I/O2)
m1_data3: U31.12 (1Y3), U32.12 (1Y3), U33.17 (I/O3)
m1_data4: U31.3 (2Y0), U32.3 (2Y0), U33.18 (I/O4)
m1_data5: U31.5 (2Y1), U32.5 (2Y1), U33.19 (I/O5)
m1_data6: U31.7 (2Y2), U32.7 (2Y2), U33.20 (I/O6)
m1_data7: U31.9 (2Y3), U32.9 (2Y3), U33.21 (I/O7)
m_addr0: U14.9 (Q0), U26.11 (2A3)
m_addr1: U14.7 (Q1), U24.2 (1A0)
m_addr2: U14.6 (Q2), U24.4 (1A1)
m_addr3: U14.5 (Q3), U24.6 (1A2)
m_addr4: U14.3 (Q4), U24.8 (1A3)
m_addr5: U14.2 (Q5), U24.17 (2A0)
m_addr6: U14.4 (Q6), U24.15 (2A1)
m_addr7: U14.13 (Q7), U24.13 (2A2)
m_addr8: U14.12 (Q8), U24.11 (2A3)
m_addr9: U14.14 (Q9), U25.2 (1A0)
m_addr10: U14.15 (Q10), U25.4 (1A1)
m_addr11: U14.1 (Q11), U15.10 (CLK), U25.6 (1A2)
m_addr12: U15.9 (Q0), U25.8 (1A3)
m_addr13: U15.7 (Q1), U25.17 (2A0)
m_addr14: U15.6 (Q2), U25.15 (2A1)
m_addr15: U15.5 (Q3), U25.13 (2A2)
m_addr16: U15.3 (Q4), U25.11 (2A3)
m_addr17: U15.2 (Q5)
m_addr18: U15.4 (Q6)
m_addr19: U15.13 (Q7)
m_addr20: U15.12 (Q8)
m_addr21: U15.14 (Q9)
m_addr22: U15.15 (Q10)
m_addr23: U15.1 (Q11)
output_clamp: D21.1 (K), D22.1 (K), D23.1 (K), D24.1 (K), D25.1 (K), D26.1 (K), D27.1 (K), D28.1 (K), D29.1 (K), D30.1 (K), D31.1 (K), D32.1 (K), D33.1 (K), D34.1 (K), D35.1 (K), D36.1 (K)
readwrite_toggle_flag: U1.9 (Q)
sram1_addr0: U26.9 (2Y3), U29.9 (2Y3), U33.12 (A0)
sram1_addr1: U24.18 (1Y0), U27.18 (1Y0), U33.11 (A1)
sram1_addr2: U24.16 (1Y1), U27.16 (1Y1), U33.10 (A2)
sram1_addr3: U24.14 (1Y2), U27.14 (1Y2), U33.9 (A3)
sram1_addr4: U24.12 (1Y3), U27.12 (1Y3), U33.8 (A4)
sram1_addr5: U24.3 (2Y0), U27.3 (2Y0), U33.7 (A5)
sram1_addr6: U24.5 (2Y1), U27.5 (2Y1), U33.6 (A6)
sram1_addr7: U24.7 (2Y2), U27.7 (2Y2), U33.5 (A7)
sram1_addr8: U24.9 (2Y3), U27.9 (2Y3), U33.27 (A8)
sram1_addr9: U25.18 (1Y0), U28.18 (1Y0), U33.26 (A9)
sram1_addr10: U25.16 (1Y1), U28.16 (1Y1), U33.23 (A10)
sram1_addr11: U25.14 (1Y2), U28.14 (1Y2), U33.25 (A11)
sram1_addr12: U25.12 (1Y3), U28.12 (1Y3), U33.4 (A12)
sram1_addr13: U25.3 (2Y0), U28.3 (2Y0), U33.28 (A13)
sram1_addr14: U25.5 (2Y1), U28.5 (2Y1), U33.3 (A14)
sram1_addr15: U25.7 (2Y2), U28.7 (2Y2), U33.31 (A15)
sram1_addr16: U25.9 (2Y3), U28.9 (2Y3), U33.2 (A16)
write_ready9thbit: U29.7 (2Y2)

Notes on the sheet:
Bus interrupt
pagecounter is unneeded for 1 chip but its already in the package
14.318Mhz clock gen
pull the int flag low when in use video side has priority
non-inverting required here
Bus Connection
BRIGHTNESS
with using 1 ram chip, VBLANK is the same thing as "interrupt" once the first 16 lines are counted out, vblank turns off memory must be available to read this same flag flips the buffers
HSYNC input
2 bit counter for A or B mem bank switching 1 frame = 2 vresets / 2 ntsc fields counts out 2 frames / 4 fields
Color Delay Line
Horizontal Blank Enable
white color pixel same phase as colorburst source
Vertical Reset
read-from-bus
notes
74HC154 & 74ACH541 - pull both E0 & E1 low to enable output hold H to disable output
PIXEL input
brightness select
Horizontal reset
Memory bank A
Pixel Drive Enable
color black = turn off pixel input 74x154 is active-low
Horizontal & Vertical Line Counter
COLORBURST input
if this were dual buffered / dual ram chip - connect bus_interrupt_flag to the field/page counter
Colorburst Disable
Colorburst Enable
Memory Address Counter
ignore the bus flag if _vblank switches off
can be upgraded to 6x CD74HC190 for preset/preload gives ability to draw sprites
BIAS
Horizontal Blank Disable
Output Amplifier
toggle memory-to-bus connection
need some way to indicate the bus was updated without clock control signals
Vertical Blank

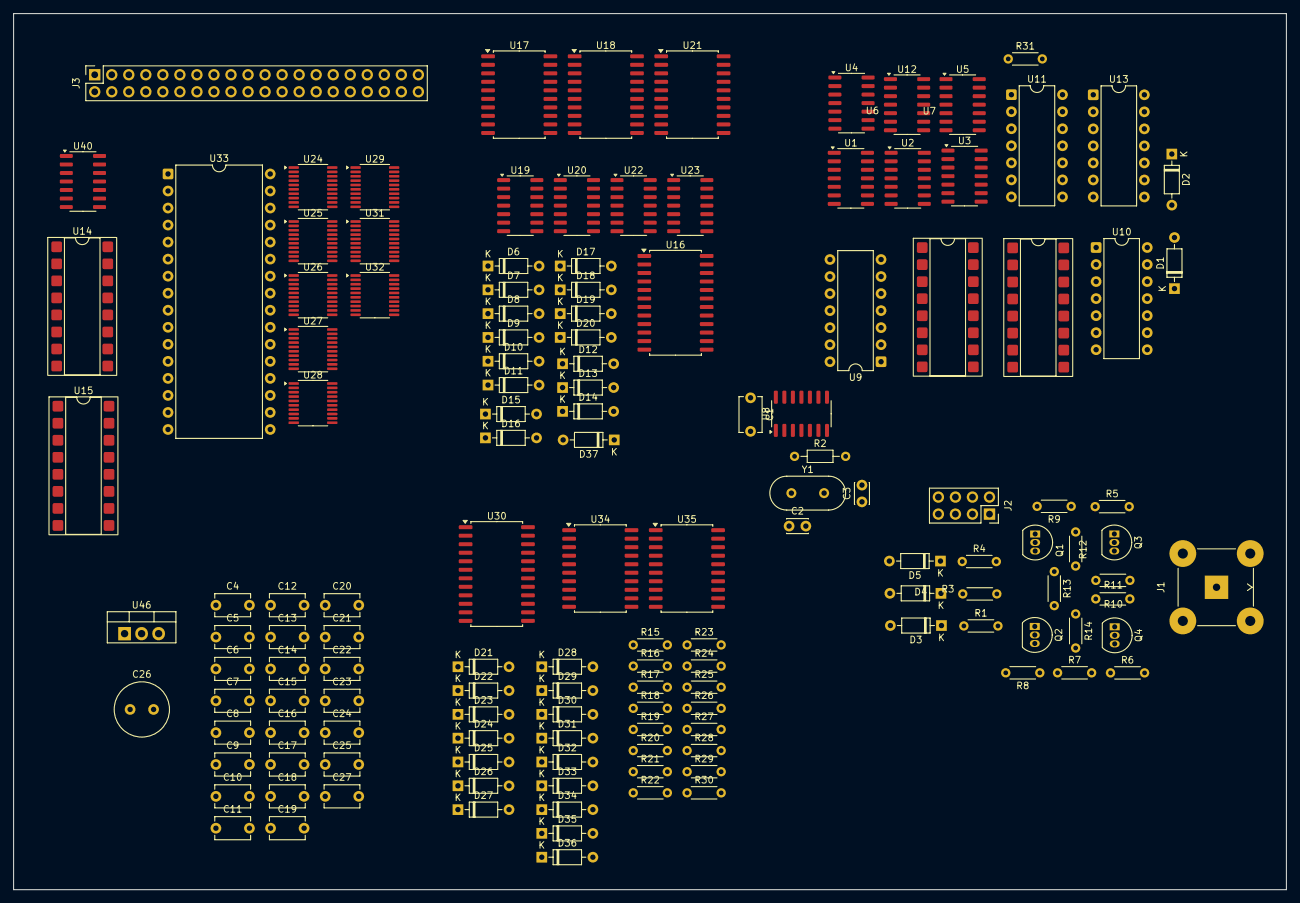
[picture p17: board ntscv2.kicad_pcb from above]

Board: 2 copper layers, 189.8 x 130.6 mm, 140 parts (0 on the bottom side), 254 nets, no tracks yet.

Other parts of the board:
D37: 1N4148; D_DO-35_SOD27_P7.62mm_Horizontal

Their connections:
colorburst_delayline: D37.1 (K); also elsewhere on the board

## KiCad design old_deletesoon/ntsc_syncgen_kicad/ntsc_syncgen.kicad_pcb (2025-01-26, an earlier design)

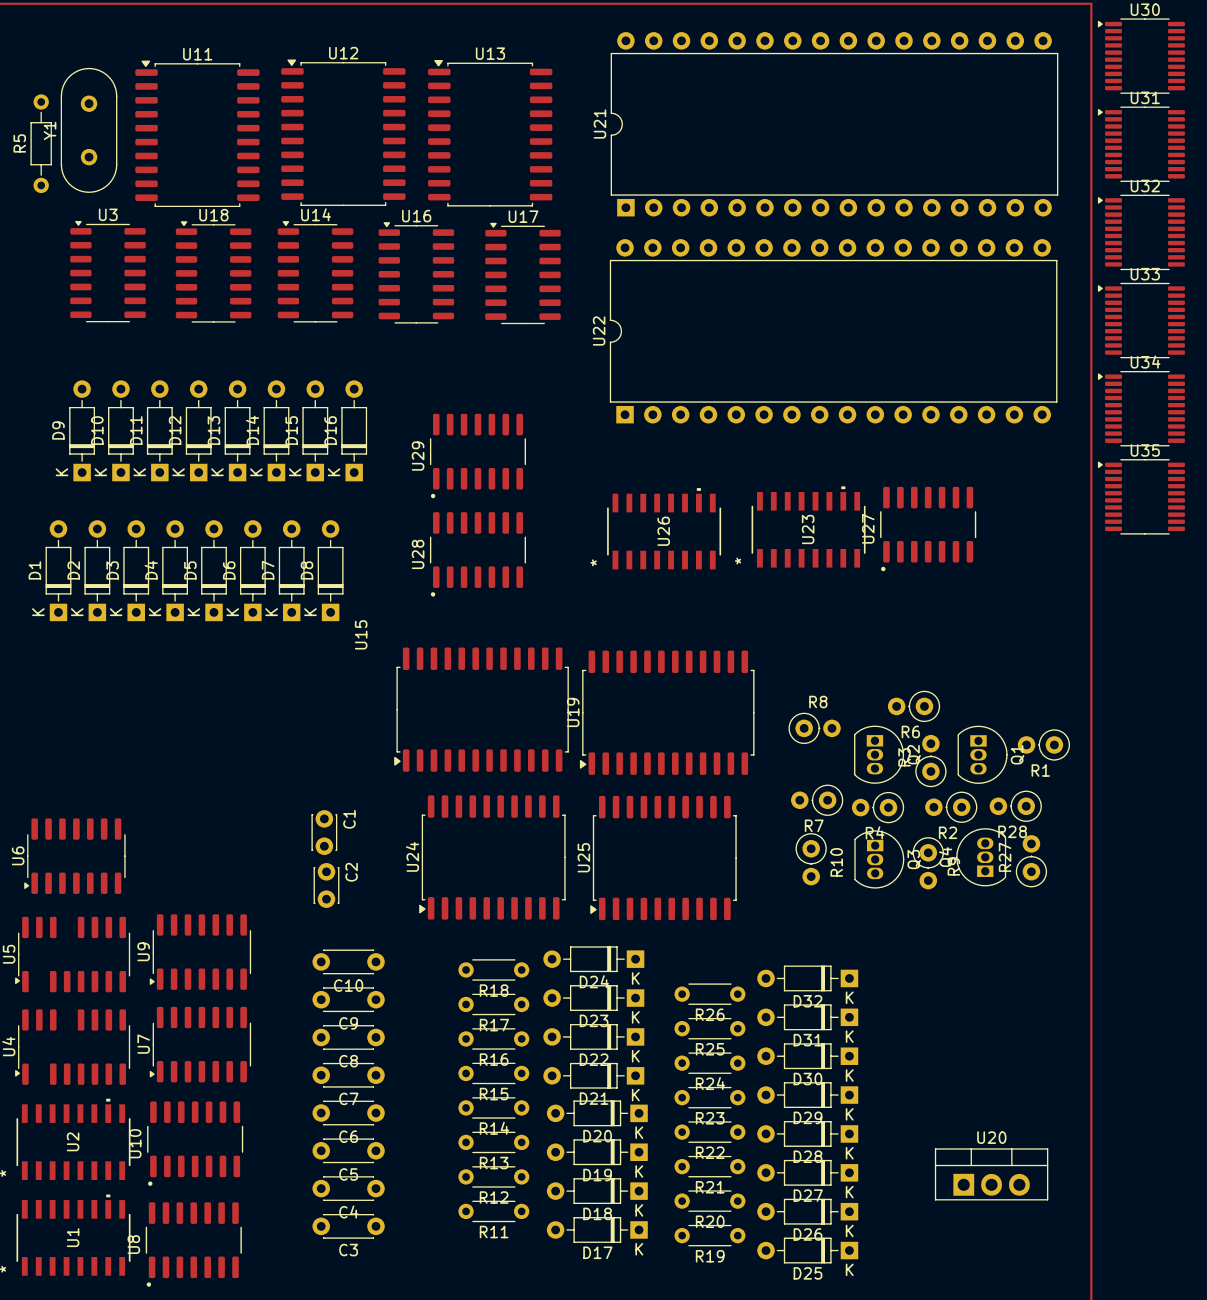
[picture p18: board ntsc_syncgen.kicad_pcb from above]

Board: 2 copper layers, 110 parts (0 on the bottom side), 175 nets, no tracks yet.

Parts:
C1, C2: 10pF; C_Disc_D3.0mm_W2.0mm_P2.50mm
C3, C4, C5, C6, C7, C8, C9, C10: C; C_Disc_D4.3mm_W1.9mm_P5.00mm
D1, D2, D3, D4, D5, D6, D7, D8, D9, D10, D11, D12, D13, D14, D15, D16, D17, D18, D19, D20, D21, D22, D23, D24, D25, D26, D27, D28, D29, D30, D31, D32: 1N4148; D_DO-35_SOD27_P7.62mm_Horizontal
Q1, Q3, Q4: 2N7000; TO-92_Inline
Q2: BC212; TO-92_Inline
R1, R27: 600R; R_Axial_DIN0207_L6.3mm_D2.5mm_P2.54mm_Vertical
R2: 30R; R_Axial_DIN0207_L6.3mm_D2.5mm_P2.54mm_Vertical
R3: 40R; R_Axial_DIN0207_L6.3mm_D2.5mm_P2.54mm_Vertical
R4: 400R; R_Axial_DIN0207_L6.3mm_D2.5mm_P2.54mm_Vertical
R5: 680; R_Axial_DIN0204_L3.6mm_D1.6mm_P7.62mm_Horizontal
R6: 70R; R_Axial_DIN0207_L6.3mm_D2.5mm_P2.54mm_Vertical
R7: 140R; R_Axial_DIN0207_L6.3mm_D2.5mm_P2.54mm_Vertical
R8: 75R; R_Axial_DIN0207_L6.3mm_D2.5mm_P2.54mm_Vertical
R9: 800R; R_Axial_DIN0207_L6.3mm_D2.5mm_P2.54mm_Vertical
R10: 15R; R_Axial_DIN0207_L6.3mm_D2.5mm_P2.54mm_Vertical
R11, R12, R13, R14, R15, R16, R17, R18, R19, R20, R21, R22, R23, R24, R25, R26: R; R_Axial_DIN0204_L3.6mm_D1.6mm_P5.08mm_Horizontal
R28: 35R; R_Axial_DIN0207_L6.3mm_D2.5mm_P2.54mm_Vertical
U1, U2, U23, U26: 74HC4040D; SOT109-1_NXP
U3: 74HC7014; SOIC-14_3.9x8.7mm_P1.27mm
U4, U5: 74HC00; SOIC-14-16_3.9x9.9mm_P1.27mm
U6: 74HC00; SOIC-14_3.9x8.7mm_P1.27mm
U7: 4081; SOIC-14_3.9x8.7mm_P1.27mm
U8, U10, U27, U28, U29: 74HC74; SOIC127P600X175-14N
U9: 4001; SOIC-14_3.9x8.7mm_P1.27mm
U11, U12, U13: 74AHC541; SOIC-20W_7.5x12.8mm_P1.27mm
U14, U16, U17, U18: 74HC02; SOIC-14_3.9x8.7mm_P1.27mm
U15, U19: 74154; SOIC-24W_7.5x15.4mm_P1.27mm
U20: LM7805_TO220; TO-220-3_Vertical
U21, U22: HM628128ALFP-5; DIP-32_W15.24mm
U24, U25: 74HC540D_653; SOIC-20W_7.5x12.8mm_P1.27mm
U30, U31, U32, U33, U34, U35: 74HC244; SSOP-20_4.4x6.5mm_P0.65mm
Y1: Crystal; Crystal_HC49-U_Vertical

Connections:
1H: U2.9 (Q0), U11.2 (A0), U14.2
1V: U1.9 (Q0), U6.5
2H: U2.7 (Q1), U7.1
4H: U2.6 (Q2), U7.2
4V: U1.6 (Q2), U4.10, U6.2
7.1mhz_CLK1: U2.10 (CP*), U8.5 (Q), U10.3 (C), U27.3 (C)
8V: U1.5 (Q3), U4.4, U4.5
16H: U2.3 (Q4), U5.1
16V: U1.3 (Q4), U9.13
64H: U2.4 (Q6), U7.5
128H: U2.13 (Q7), U7.6
256H: U2.12 (Q8), U7.13
256V: U1.12 (Q8), U6.1
COMPOSITE_OUT: R7.2, R8.1, R10.1
GND: C1.2, C2.2, C3.2, C4.2, C5.2, C6.2, C7.2, C8.2, C9.2, C10.2, Q1.1 (S), Q3.1 (S), Q4.1 (S), R1.1, R4.2, R8.2, R9.1, R27.1, U1.8 (GND), U2.8 (GND), U3.7 (GND), U4.7 (GND), U5.7 (GND), U6.7 (GND), U7.7 (VSS), U8.7 (GND), U9.7 (VSS), U10.7 (GND), U11.10 (GND), U12.10 (GND), U13.10 (GND), U20.2 (GND), U23.8 (GND), U26.8 (GND)
HRESET: U1.10 (CP*), U2.11 (MR), U10.6 (~Q), U10.11 (C)
unnamed: C1.1, U3.1, Y1.1
unnamed: C2.1, R5.2, Y1.2
unnamed: D1.2 (A), U14.1
unnamed: D2.2 (A), U14.4
unnamed: D3.2 (A), U14.10
unnamed: D4.2 (A), U14.13
unnamed: D5.2 (A), U16.1
unnamed: D6.2 (A), U16.4
unnamed: D7.2 (A), U16.10
unnamed: D8.2 (A), U17.1
unnamed: D9.2 (A), U17.4
unnamed: D10.2 (A), U17.10
unnamed: D11.2 (A), U17.13
unnamed: D12.2 (A), U18.1
unnamed: D13.2 (A), U18.4
unnamed: D14.2 (A), U18.10
unnamed: D15.2 (A), U18.13
unnamed: D16.2 (A), U16.13
unnamed: D17.2 (A), R11.2
unnamed: D18.2 (A), R12.2
unnamed: D19.2 (A), R13.2
unnamed: D20.2 (A), R14.2
unnamed: D21.2 (A), R16.2
unnamed: D22.2 (A), R17.2
unnamed: D23.2 (A), R18.2
unnamed: D24.2 (A), R15.2
unnamed: D25.2 (A), R19.2
unnamed: D26.2 (A), R20.2
unnamed: D27.2 (A), R21.2
unnamed: D28.2 (A), R22.2
unnamed: D29.2 (A), R23.2
unnamed: D30.2 (A), R24.2
unnamed: D31.2 (A), R25.2
unnamed: D32.2 (A), R26.2
unnamed: Q1.3 (D), R3.2
unnamed: Q2.2 (B), R6.2
unnamed: Q2.3 (E), R7.1
unnamed: Q3.3 (D), R10.2
unnamed: Q4.3 (D), R28.1
unnamed: R2.2, R3.1, R4.1, R6.1, R28.2
unnamed: R5.1, U3.2, U3.3
unnamed: U4.3, U4.9
unnamed: U5.3, U5.9
unnamed: U5.6, U5.10, U5.12
unnamed: U6.3, U6.4
unnamed: U7.3, U7.8
unnamed: U7.9, U7.11
unnamed: U7.4, U7.12
unnamed: U3.4, U8.3 (C)
unnamed: U8.2 (D), U8.6 (~Q)
unnamed: U7.10, U10.2 (D)
unnamed: U6.6, U10.12 (D)
unnamed: U11.3 (A1), U11.18 (Y0)
unnamed: U11.4 (A2), U11.17 (Y1)
unnamed: U11.5 (A3), U11.16 (Y2)
unnamed: U11.6 (A4), U11.15 (Y3)
unnamed: U11.7 (A5), U11.14 (Y4)
unnamed: U11.8 (A6), U11.13 (Y5)
unnamed: U11.9 (A7), U11.12 (Y6)
unnamed: U11.1 (G1), U11.19 (G2)
unnamed: U11.11 (Y7), U12.9 (A7)
unnamed: U12.2 (A0), U12.17 (Y1)
unnamed: U12.3 (A1), U12.16 (Y2)
unnamed: U12.4 (A2), U12.15 (Y3)
unnamed: U12.5 (A3), U12.14 (Y4)
unnamed: U12.6 (A4), U12.13 (Y5)
unnamed: U12.7 (A5), U12.12 (Y6)
unnamed: U12.8 (A6), U12.11 (Y7)
unnamed: U12.1 (G1), U12.19 (G2)
unnamed: U12.18 (Y0), U13.2 (A0)
unnamed: U13.3 (A1), U13.18 (Y0)
unnamed: U13.4 (A2), U13.17 (Y1)
unnamed: U13.5 (A3), U13.16 (Y2)
unnamed: U13.6 (A4), U13.15 (Y3)
unnamed: U13.7 (A5), U13.14 (Y4)
unnamed: U13.8 (A6), U13.13 (Y5)
unnamed: U13.9 (A7), U13.12 (Y6)
unnamed: U13.1 (G1), U13.19 (G2)
unnamed: R11.1, U24.18 (~Y0)
unnamed: R12.1, U24.17 (~Y1)
unnamed: R13.1, U24.16 (~Y2)
unnamed: R14.1, U24.15 (~Y3)
unnamed: R16.1, U24.14 (~Y4)
unnamed: R17.1, U24.13 (~Y5)
unnamed: R18.1, U24.12 (~Y6)
unnamed: R15.1, U24.11 (~Y7)
unnamed: R19.1, U25.18 (~Y0)
unnamed: R21.1, U25.17 (~Y1)
unnamed: R23.1, U25.16 (~Y2)
unnamed: R25.1, U25.15 (~Y3)
unnamed: R20.1, U25.14 (~Y4)
unnamed: R22.1, U25.13 (~Y5)
unnamed: R24.1, U25.12 (~Y6)
unnamed: R26.1, U25.11 (~Y7)
unnamed: U27.2 (D), U27.6 (~Q)
unnamed: U28.2 (D), U28.6 (~Q)
unnamed: U28.5 (Q), U29.3 (C)
VBLANK: U4.1, U9.9, U9.11
VCC: C3.1, C4.1, C5.1, C6.1, C7.1, C8.1, C9.1, C10.1, Q2.1 (C), R2.1, U1.16 (VCC), U2.16 (VCC), U3.14 (VCC), U4.14 (VCC), U5.14 (VCC), U6.14 (VCC), U7.14 (VDD), U8.1 (~R), U8.4 (~S), U8.14 (VCC), U9.14 (VDD), U10.1 (~R), U10.4 (~S), U10.10 (~S), U10.13 (~R), U10.14 (VCC), U11.20 (VCC), U12.20 (VCC), U13.20 (VCC), U18.11, U20.3 (VO), U23.16 (VCC), U26.16 (VCC), U27.1 (~R), U27.4 (~S), U28.1 (~R), U28.4 (~S), U29.1 (~R), U29.4 (~S)
VRESET: U1.11 (MR), U9.8, U10.8 (~Q), U28.3 (C)
_HBLANK: U5.8, U9.5
_HRESET: U5.5, U10.5 (Q)
_VBLANK: U9.6, U9.10, U9.12
_VRESET: U10.9 (Q), U23.11 (MR), U26.11 (MR)
_fieldcounter: U29.2 (D), U29.6 (~Q)
bias_input: Q4.2 (G), R27.2
colorburst_delayline: D1.1 (K), D2.1 (K), D3.1 (K), D4.1 (K), D5.1 (K), D6.1 (K), D7.1 (K), D8.1 (K), D9.1 (K), D10.1 (K), D11.1 (K), D12.1 (K), D13.1 (K), D14.1 (K), D15.1 (K), D16.1 (K)
colorselect1: U14.3, U15.1 (~S0)
colorselect2: U14.6, U15.2 (~S1)
colorselect3: U14.9, U15.3 (~S2)
colorselect4: U14.12, U15.4 (~S3)
colorselect5: U15.5 (~S4), U16.3
colorselect6: U15.6 (~S5), U16.6
colorselect7: U15.7 (~S6), U16.9
colorselect8: U15.8 (~S7), U16.12
colorselect9: U15.9 (~S8), U17.3
colorselect10: U15.10 (~S9), U17.6
colorselect11: U15.11 (~S10), U17.9
colorselect12: U15.13 (~S11), U17.12
colorselect13: U15.14 (~S12), U18.3
colorselect14: U15.15 (~S13), U18.6
colorselect15: U15.16 (~S14), U18.9
colorselect16: U15.17 (~S15), U18.12
luminosity_select1: U19.1 (~S0), U24.2 (A0)
luminosity_select2: U19.2 (~S1), U24.3 (A1)
luminosity_select3: U19.3 (~S2), U24.4 (A2)
luminosity_select4: U19.4 (~S3), U24.5 (A3)
luminosity_select5: U19.5 (~S4), U24.6 (A4)
luminosity_select6: U19.6 (~S5), U24.7 (A5)
luminosity_select7: U19.7 (~S6), U24.8 (A6)
luminosity_select8: U19.8 (~S7), U24.9 (A7)
luminosity_select9: U19.9 (~S8), U25.2 (A0)
luminosity_select10: U19.10 (~S9), U25.3 (A1)
luminosity_select11: U19.11 (~S10), U25.4 (A2)
luminosity_select12: U19.13 (~S11), U25.5 (A3)
luminosity_select13: U19.14 (~S12), U25.6 (A4)
luminosity_select14: U19.15 (~S13), U25.7 (A5)
luminosity_select15: U19.16 (~S14), U25.8 (A6)
luminosity_select16: U19.17 (~S15), U25.9 (A7)
m_addr0: U26.9 (Q0), U30.11 (2A3), U31.11 (2A3)
m_addr1: U26.7 (Q1), U33.2 (1A0), U34.2 (1A0)
m_addr2: U26.6 (Q2), U33.4 (1A1), U34.4 (1A1)
m_addr3: U26.5 (Q3), U33.6 (1A2), U34.6 (1A2)
m_addr4: U26.3 (Q4), U33.8 (1A3), U34.8 (1A3)
m_addr5: U26.2 (Q5), U33.17 (2A0), U34.17 (2A0)
m_addr6: U26.4 (Q6), U33.15 (2A1), U34.15 (2A1)
m_addr7: U26.13 (Q7), U33.13 (2A2), U34.13 (2A2)
m_addr8: U26.12 (Q8), U33.11 (2A3), U34.11 (2A3)
m_addr9: U26.14 (Q9), U32.2 (1A0), U35.2 (1A0)
m_addr10: U26.15 (Q10), U32.4 (1A1), U35.4 (1A1)
m_addr11: U23.10 (CP*), U26.1 (Q11), U32.6 (1A2), U35.6 (1A2)
m_addr12: U23.7 (Q1), U32.8 (1A3), U35.8 (1A3)
m_addr13: U23.6 (Q2), U32.17 (2A0), U35.17 (2A0)
m_addr14: U23.5 (Q3), U32.15 (2A1), U35.15 (2A1)
m_addr15: U23.3 (Q4), U32.13 (2A2), U35.13 (2A2)
m_addr16: U23.2 (Q5), U32.11 (2A3), U35.11 (2A3)
output_clamp: Q3.2 (G), R9.2
ramclock: U26.10 (CP*), U27.5 (Q)
video_amplifier_input: Q1.2 (G), R1.2

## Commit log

2024-10-27 example circuit
    [ntsc_syncgen.kicad_pcb, ntsc_syncgen.kicad_sch]
2024-12-24 more work
    [SN74AHC74DR.step, ntsc_syncgen.kicad_pcb, ntsc_syncgen.kicad_sch]
2025-01-26 updated project
    [74HC540D_653.step, SN74AHC74DR.step, ntsc_syncgen.kicad_pcb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]
2025-03-31 removed old version added new one
    [74HC540D_653.step, SN74AHC74DR.step, ntsc_syncgen.kicad_pcb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]
2025-04-22 lots of work
    [74HC540D_653.step, SN74AHC74DR.step, ntsc_syncgen.kicad_pcb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]
2025-07-23 added first test version
    created a small 100x100mm test version on 4 layer
    [3362P-1-100LF.step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]
